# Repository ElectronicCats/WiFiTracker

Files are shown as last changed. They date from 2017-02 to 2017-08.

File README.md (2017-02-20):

# WiFiTracker

Based in the work of [zoutepopcorn](https://github.com/zoutepopcorn/hoeks.ma)

Electronic Cats invests time and resources providing this open source design, please support Electronic Cats and open-source hardware by purchasing products from Electronic Cats!

Designed by Electronic Cats.

Firmware released under an GNU AGPL v3.0 license. See the LICENSE file for more information.

Hardware released under an CERN Open Hardware Licence v1.2. See the LICENSE_HARDWARE file for more information.

Electronic Cats is a registered trademark, please do not use if you sell these PCBs.

20 Feb 2017

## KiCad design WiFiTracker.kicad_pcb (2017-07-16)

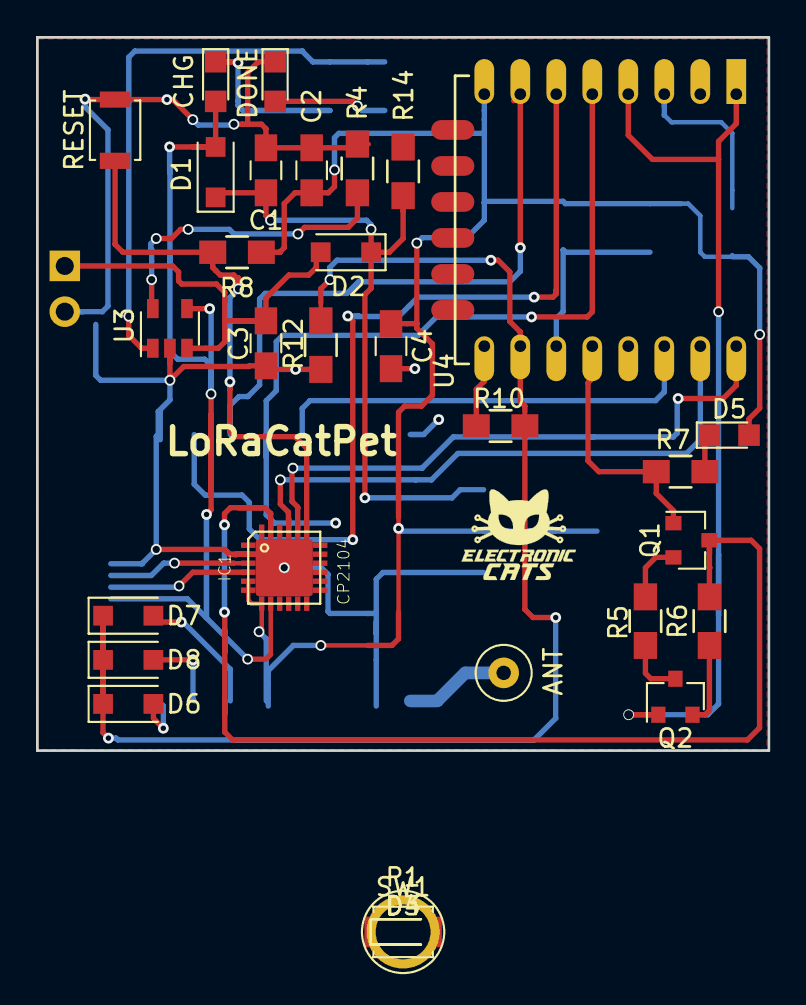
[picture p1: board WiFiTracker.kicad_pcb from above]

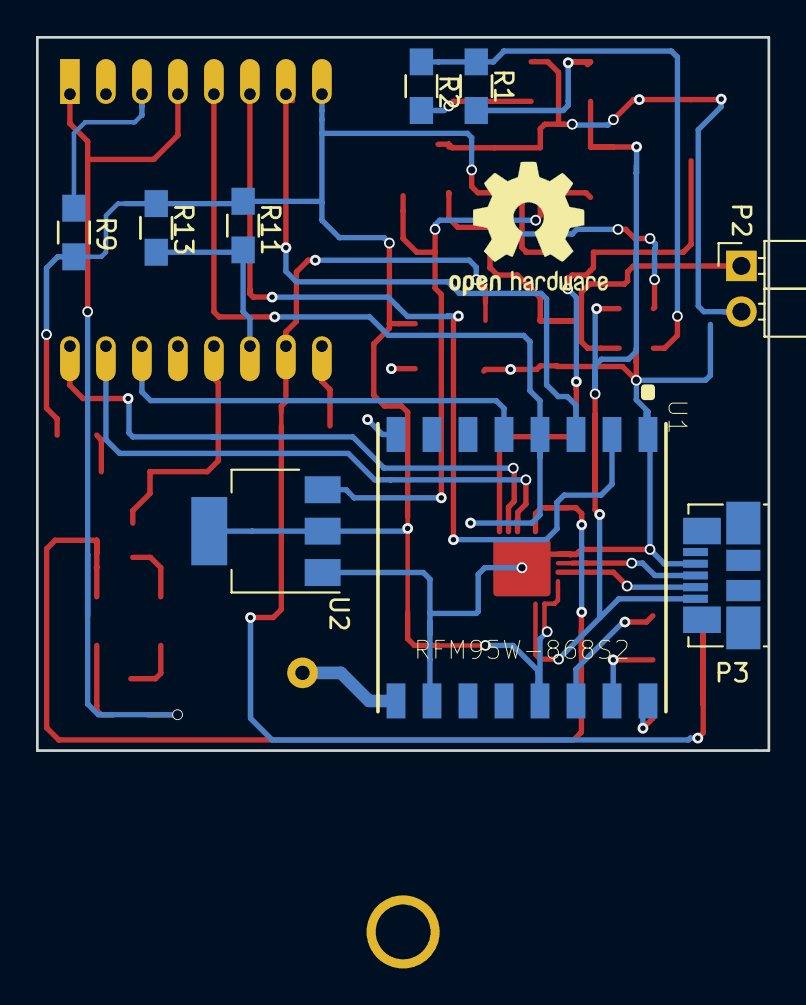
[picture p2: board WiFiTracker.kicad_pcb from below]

Board: 2 copper layers, 40.6 x 39.6 mm, 40 parts (9 on the bottom side), 31 nets.

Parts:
ANT: ANT; 1pin
C1, C2: 4.7uF; C_0805_HandSoldering
C3, C4: 10uF; C_0805_HandSoldering
CHG: CHG; LED_0805
D1, D2: D_Schottky; D_SOD-123F
D3: CHG; LED_0805
D4: DONE; LED_0805
D5: Led; LED_0805
D6, D7, D8: D; D_SOD-123F
DONE: DONE; LED_0805
IC1: CP2104; QFN24-PAD
P1: ANT; 1pin
P2: Battery; Pin_Header_Angled_1x02_Pitch2.54mm
P3: USB_B; USB_Micro-B_Molex_47346-0001
Q1, Q2: MMBT2222A; SOT-23
R1, R2, R7: 330R; R_0805_HandSoldering
R4, R5, R6, R8, R9, R10, R11, R12, R13, R14: 10K; R_0805_HandSoldering
RESET: SW_RESET; SW_SPST_B3U-1000P
SW1: SW_RESET; SW_SPST_B3U-1000P
U1: RFM95W-868S2; XCVR_RFM95W-868S2
U2: AP2114; SOT-223-3Lead_TabPin2
U3: MCP73831T-2ATI/OT; SOT-23-5
U4: ESP8266-12E; ESP-12E

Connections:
+3V3: C2.1, C4.1, D5.2, IC1.5, IC1.6, IC1.7, R8.1, R9.1, R11.1, R13.1, U1.13, U2.2, U4.8
+BATT: C3.1, D2.2, P2.1, U3.3
/CH_PD: R9.2, U4.3
/DIO0: D7.2, U1.14
/DIO1: D8.2, U1.15
/DIO2: D6.2, U1.16
/DTR: IC1.23, Q1.3, R6.2
/GPIO0: Q1.1, R7.1, U4.18
/GPIO2: R11.2, R13.2, U4.17
/GPIO5: U1.5, U4.20
/GPIO12: U1.2, U4.6
/GPIO13: U1.3, U4.7
/GPIO14: U1.4, U4.5
/GPIO15: D6.1, D7.1, D8.1, R10.1, R12.1, U4.16
/RESET: Q2.1, R8.2, SW1.2, U4.1, U4.4
/RTS: IC1.19, Q2.3, R5.2
/RXD: IC1.21, U4.21
/TXD: IC1.20, U4.22
GND: C1.2, C2.2, C3.2, C4.2, D4.1, DONE.1, IC1.2, IC1.TP, P2.2, P3.4, R4.2, R10.2, R12.2, RESET.1, SW1.1, U1.1, U1.8, U1.10, U2.1, U3.2, U4.15
unnamed: C1.1, D1.1, D2.1, R14.2, U2.3
unnamed: CHG.1, D3.1, R1.2
unnamed: D4.2, DONE.2, R2.2
unnamed: D5.1, R7.2
unnamed: IC1.3, P3.3
unnamed: IC1.4, P3.2
unnamed: ANT.1, P1.1, U1.9
unnamed: Q1.2, R5.1
unnamed: Q2.2, R6.1
unnamed: R1.1, R2.1, U3.1
unnamed: R4.1, U3.5
VCC: CHG.2, D1.2, D3.2, IC1.8, P3.1, U3.4

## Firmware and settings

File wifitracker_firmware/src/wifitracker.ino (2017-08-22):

/*******************************************************************************
 * Copyright (c) 2015 Matthijs Kooijman and Thomas Telkamp
 *
 * HLC (Hoeks.ma Location) .ino file edited by Johan Hoeksma
 * You will need a esp8266
 *
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
 * This example sends a valid LoRaWAN packet with payload "Hello, world!", that
 * will be processed by The Things Network server.
 *
 * Change DEVADDR to a unique address!
 *
 * Do not forget to define the radio type correctly in config.h, default is:
 *   #define CFG_sx1272_radio 1
 * for SX1272 and RFM92, but change to:
 *   #define CFG_sx1276_radio 1
 * for SX1276 and RFM95.
 *
 *
 *******************************************************************************/
#include "ESP8266WiFi.h"
#include <lmic.h>
#include <hal/hal.h>
#include <SPI.h>
#include <Arduino.h>
#include <ESP8266WiFiMulti.h>
#include <ESP8266HTTPClient.h>
#include <ESP8266httpUpdate.h>
#include <EEPROM.h>

#define USE_SERIAL Serial

// use ttn dashboard to get this keys
static const PROGMEM u1_t NWKSKEY[16] = { 0xE2, 0x6C, 0xFD, 0xC2, 0x5B, 0x80, 0x87, 0xD3, 0x9E, 0xBB, 0x63, 0xCD, 0xBD, 0xE5, 0xF3, 0x7B };
static const u1_t PROGMEM APPSKEY[16] = { 0xC0, 0x73, 0xC8, 0x60, 0xB2, 0xF3, 0xF2, 0x64, 0x94, 0xF2, 0xAB, 0x80, 0xB6, 0x3D, 0x4B, 0x75 };
static const u4_t DEVADDR = 0x2601173B; // <-- Change this address for every node!

// WiFi vars
static const int NR_MACS = 3;
static uint8_t mydata[] = "test";
uint8_t macs[NR_MACS * 7];    // Array to store the 4 mac for  // (nrMacs * 7) + nrMacs
char buffer[64];

const int sleepTimeS = 60;

ADC_MODE(ADC_VCC); // enables reading the ESP8266 supply voltage

void os_getArtEui (u1_t* buf) { }
void os_getDevEui (u1_t* buf) { }
void os_getDevKey (u1_t* buf) { }

ESP8266WiFiMulti WiFiMulti;

static osjob_t sendjob;

// Schedule TX every this many seconds (might become longer due to duty
// cycle limitations).
const unsigned TX_INTERVAL = 60;

// The LORAWAN session state is saved in EEPROM
// Here just the frame sequence number is saved as its ABP with a Single Channel Gateway,
// See http://forum.thethingsnetwork.org/t/new-backend-how-to-connect/1983/91
#define INITED_FLAG 0x12344321 // <<<< Change this to have the frame sequence restart from zero
typedef struct {
  uint32 inited;
  u4_t seqnoUp;
} LORA_STATE;
LORA_STATE loraState;

// Pin mapping ESP8266   D1 -> Slave select
const lmic_pinmap lmic_pins = {
    .nss = D1,
    .rxtx = LMIC_UNUSED_PIN,
    .rst = LMIC_UNUSED_PIN,
    .dio = {LMIC_UNUSED_PIN, LMIC_UNUSED_PIN, LMIC_UNUSED_PIN},
};

void ota() {
    USE_SERIAL.println();
    USE_SERIAL.println();
    Serial.println("ota");
    WiFiMulti.addAP("ssid", "12345678");
    for(uint8_t t = 5; t > 0; t--) {
        USE_SERIAL.printf("[SETUP] WAIT %d...\n", t);
        USE_SERIAL.flush();
        delay(1000);
    }

    Serial.println("setup complete");
    delay(5000);
    if(WiFiMulti.run() != WL_CONNECTED)  {
        Serial.println("No wifi update shutting down wifi");
    } else {
        Serial.println("updating");
        t_httpUpdate_return ret = ESPhttpUpdate.update("http://server.nl/ota.bin");

        switch(ret) {
            case HTTP_UPDATE_FAILED:
                USE_SERIAL.printf("HTTP_UPDATE_FAILD Error (%d): %s", ESPhttpUpdate.getLastError(), ESPhttpUpdate.getLastErrorString().c_str());
                break;

            case HTTP_UPDATE_NO_UPDATES:
                USE_SERIAL.println("HTTP_UPDATE_NO_UPDATES");
                break;

            case HTTP_UPDATE_OK:
                USE_SERIAL.println("HTTP_UPDATE_OK");
                break;
        }
    }
}

boolean hasLocation() {
  digitalWrite(D2, HIGH);
  int n = WiFi.scanNetworks(); // number of acces points found
  if (n == 0) {
    Serial.println("Nope. No spots, are you lost or what :(");
    return false;
  } else {
    Serial.print("I found ");
    Serial.print(n);
    Serial.println(" spots!");
    if(n > NR_MACS) {
      n = NR_MACS;
    }
    // TODO: send only strongest RSSI??
    for (int i = 0; i < n; ++i) {
        Serial.println();
        Serial.print("rssi");
        Serial.println(WiFi.RSSI(i));
        for(int c = 0; c < 6; c++) {
            macs[(i * 7) + c] = (uint8_t)WiFi.BSSID(i)[c];
            Serial.print(WiFi.BSSID(i)[c]);
            Serial.print(":");
        }
        Serial.println();
        macs[(i*7)+6] =  (uint8_t)((-1) * WiFi.RSSI(i));
      delay(10);
    }
  }
  Serial.println("");
  return true;
}

void goToSleep() {

  loraState.seqnoUp = LMIC.seqnoUp;
  EEPROM.put(0, loraState);
  EEPROM.end();
  Serial.print("loraState.seqnoUp = "); Serial.println(loraState.seqnoUp);
  Serial.println("Sleep...");
  ESP.deepSleep(sleepTimeS * 1000000);
}

void do_send(osjob_t* j){
    if (LMIC.opmode & OP_TXRXPEND) {
        Serial.println(F("OP_TXRXPEND, not sending"));
    } else {
        if(hasLocation()) {
          LMIC_setTxData2(1, macs, sizeof(macs), 0);
        } else {
          LMIC_setTxData2(1, mydata, sizeof(mydata), 0);
        }
        Serial.println(F("Packet queued"));
    }
    // Next TX is scheduled after TX_COMPLETE event.
}

void onEvent (ev_t ev) {
    Serial.print(os_getTime());
    Serial.print(": ");
    switch(ev) {
        case EV_SCAN_TIMEOUT:
            Serial.println(F("EV_SCAN_TIMEOUT"));
            break;
        case EV_BEACON_FOUND:
            Serial.println(F("EV_BEACON_FOUND"));
            break;
        case EV_BEACON_MISSED:
            Serial.println(F("EV_BEACON_MISSED"));
            break;
        case EV_BEACON_TRACKED:
            Serial.println(F("EV_BEACON_TRACKED"));
            break;
        case EV_JOINING:
            Serial.println(F("EV_JOINING"));
            break;
        case EV_JOINED:
            Serial.println(F("EV_JOINED"));
            break;
        case EV_RFU1:
            Serial.println(F("EV_RFU1"));
            break;
        case EV_JOIN_FAILED:
            Serial.println(F("EV_JOIN_FAILED"));
            break;
        case EV_REJOIN_FAILED:
            Serial.println(F("EV_REJOIN_FAILED"));
            break;
        case EV_TXCOMPLETE:
            Serial.println(F("EV_TXCOMPLETE (includes waiting for RX windows)"));
            if (LMIC.txrxFlags & TXRX_ACK)
              Serial.println(F("Received ack"));
            if (LMIC.dataLen) {
              Serial.println(F("Received "));
              Serial.println(LMIC.dataLen);
              Serial.println(F(" bytes of payload"));
            }
            digitalWrite(D2, LOW);
            // Schedule next transmission
            os_setTimedCallback(&sendjob, os_getTime()+sec2osticks(TX_INTERVAL), do_send);
            goToSleep();
            break;
        case EV_LOST_TSYNC:
            Serial.println(F("EV_LOST_TSYNC"));
            break;
        case EV_RESET:
            Serial.println(F("EV_RESET"));
            break;
        case EV_RXCOMPLETE:
            // data received in ping slot
            Serial.println(F("EV_RXCOMPLETE"));
            break;
        case EV_LINK_DEAD:
            Serial.println(F("EV_LINK_DEAD"));
            break;
        case EV_LINK_ALIVE:
            Serial.println(F("EV_LINK_ALIVE"));
            break;
         default:
            Serial.println(F("Unknown event"));
            break;
    }
}

void setup() {
    Serial.begin(115200);

    EEPROM.begin(sizeof(loraState));
 EEPROM.get(0, loraState);
 if (loraState.inited != INITED_FLAG) {
    loraState.inited = INITED_FLAG;
    loraState.seqnoUp = 0;
 }

    Serial.println(F("Starting"));
    WiFi.mode(WIFI_STA);
    pinMode(D2,OUTPUT);
    // check if it needs OTA update..
    ota();
    WiFi.mode(WIFI_OFF);
    digitalWrite(D2, HIGH);
    // LMIC init
    os_init();
    // Reset the MAC state. Session and pending data transfers will be discarded.
    LMIC_reset();

    #ifdef PROGMEM
    uint8_t appskey[sizeof(APPSKEY)];
    uint8_t nwkskey[sizeof(NWKSKEY)];
    memcpy_P(appskey, APPSKEY, sizeof(APPSKEY));
    memcpy_P(nwkskey, NWKSKEY, sizeof(NWKSKEY));
    LMIC_setSession (0x1, DEVADDR, nwkskey, appskey);
    #else
    // If not running an AVR with PROGMEM, just use the arrays directly
    LMIC_setSession (0x1, DEVADDR, NWKSKEY, APPSKEY);
    #endif

    #if defined(CFG_eu868)
    LMIC_setupChannel(0, 868100000, DR_RANGE_MAP(DR_SF12, DR_SF7),  BAND_CENTI);      // g-band
    LMIC_setupChannel(1, 868100000, DR_RANGE_MAP(DR_SF12, DR_SF7B), BAND_CENTI);      // g-band
    LMIC_setupChannel(2, 868100000, DR_RANGE_MAP(DR_SF12, DR_SF7),  BAND_CENTI);      // g-band
    LMIC_setupChannel(3, 868100000, DR_RANGE_MAP(DR_SF12, DR_SF7),  BAND_CENTI);      // g-band
    LMIC_setupChannel(4, 868100000, DR_RANGE_MAP(DR_SF12, DR_SF7),  BAND_CENTI);      // g-band
    LMIC_setupChannel(5, 868100000, DR_RANGE_MAP(DR_SF12, DR_SF7),  BAND_CENTI);      // g-band
    LMIC_setupChannel(6, 868100000, DR_RANGE_MAP(DR_SF12, DR_SF7),  BAND_CENTI);      // g-band
    LMIC_setupChannel(7, 868100000, DR_RANGE_MAP(DR_SF12, DR_SF7),  BAND_CENTI);      // g-band
    LMIC_setupChannel(8, 868100000, DR_RANGE_MAP(DR_FSK,  DR_FSK),  BAND_MILLI);      // g2-band
    #elif defined(CFG_us915)
      for (int channel=0; channel<72; ++channel) {
          LMIC_disableChannel(channel);
        }

          LMIC_enableChannel(48);
          LMIC_enableChannel(49);
          LMIC_enableChannel(50);
          LMIC_enableChannel(51);
          LMIC_enableChannel(52);
          LMIC_enableChannel(53);
          LMIC_enableChannel(54);
          LMIC_enableChannel(55);
          LMIC_enableChannel(70);
    #endif
    // Disable link check validation
    LMIC_setLinkCheckMode(0);
    // TTN uses SF9 for its RX2 window.
    LMIC.dn2Dr = DR_SF9;
    // Set data rate and transmit power for uplink (note: txpow seems to be ignored by the library)
    LMIC_setDrTxpow(DR_SF7,14);

    LMIC.seqnoUp = loraState.seqnoUp;

    // Start job
    do_send(&sendjob);
}

void loop() {
    os_runloop_once();
}

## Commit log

2017-02-20 Schematic 0.1
    [WiFiTracker.kicad_pcb, WiFiTracker.sch]
2017-06-08 Check PCB V0.1
    [WiFiTracker.kicad_pcb, WiFiTracker.sch]
2017-06-14 Added pin DIOs
    [WiFiTracker.sch]
2017-06-14 Update name
    [WiFiTracker.sch]
2017-06-14 Added Lib AP2114
    [WiFiTracker.kicad_pcb, WiFiTracker.sch]
2017-06-14 Arreglados los pines, se mamaron
    [WiFiTracker.kicad_pcb]
2017-07-16 Fix Reset connection
    [WiFiTracker.kicad_pcb, WiFiTracker.sch]
2017-08-22 Añadido lectura de voltaje VCC
    Por medio de Arduino puedes leer el voltaje de entrada
